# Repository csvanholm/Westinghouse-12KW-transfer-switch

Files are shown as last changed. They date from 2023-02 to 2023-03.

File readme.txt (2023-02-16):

I don't know if anybody else finds this useful? but if you do, please feel free to use this anyway you like.
I have included the schematic pdf file as well as the Kicad.sch file.
I build this on a bread board so I didn't bother with making a PCB for a one off project, but that would be easy to do 
if anyone feels the urge to do so. 

To compile this code you need to install the pico-sdk and the toolchain
there are several good tutorials on YouTube about this. (I like this one) https://www.youtube.com/watch?v=mUF9xjDtFfY

After you installed the toolchain
Create a project source directory and copy the Program.cpp and CMakeLists.txt into it.
Create a subdirectory under the source directory called build 
go into the build directory and run the command: cmake -G "Ninja" ..

After cmake is done creating the build system
Then run the command: ninja
this should build the code and generate a westinghouse12k.uf2 file   

these are the commands 
md MySrcDir
cd MySrcDir
copy Program.cpp and CMakeLists.txt files into this directory
md build
cd build
cmake -G "Ninja" ..
ninja

This controller was designed using a Pico RP2040 with a few extra external components to start,stop and detect power
of the Westinghouse WGen9500DF generator via the build-in smart switch port from a transfer-switch relay contact 
that will close when utility power fails and open when power is present.

The generator is normally started manaully using a start pushbutton or a key fob remote starter, but
it could not be hooked up directly to the transfer-switch relay since the generator needs a pulse
of a specific length to start and longer pulse stop the generator. 

The controller was designed with the following features.

1) After powering up it will wait for the generator controller to become active before 
   sending a start pulse, this is necessary because the generator controller does not
   accept commands right after power-up.

2) The Controller will try to start the generator up to 3 times if it fails after that the controller will
   "lockup" and blink all LEDs this is done to prevent draining the battery with infinite restart attempts. 
   if the generator runs out of gas or fails for some other mechanical reason (such as forgetting to open the gas spigot) 
   (Lockup is reset by turning the power off and on again)

3) When power returns the controller will run the generator in "cool down" mode for 40 seconds before stopping it,
   if power fails during cool-down, it will just keep running and exit cool-down mode.

best of luck 

carsten svanholm
csvanholm@comcast.net

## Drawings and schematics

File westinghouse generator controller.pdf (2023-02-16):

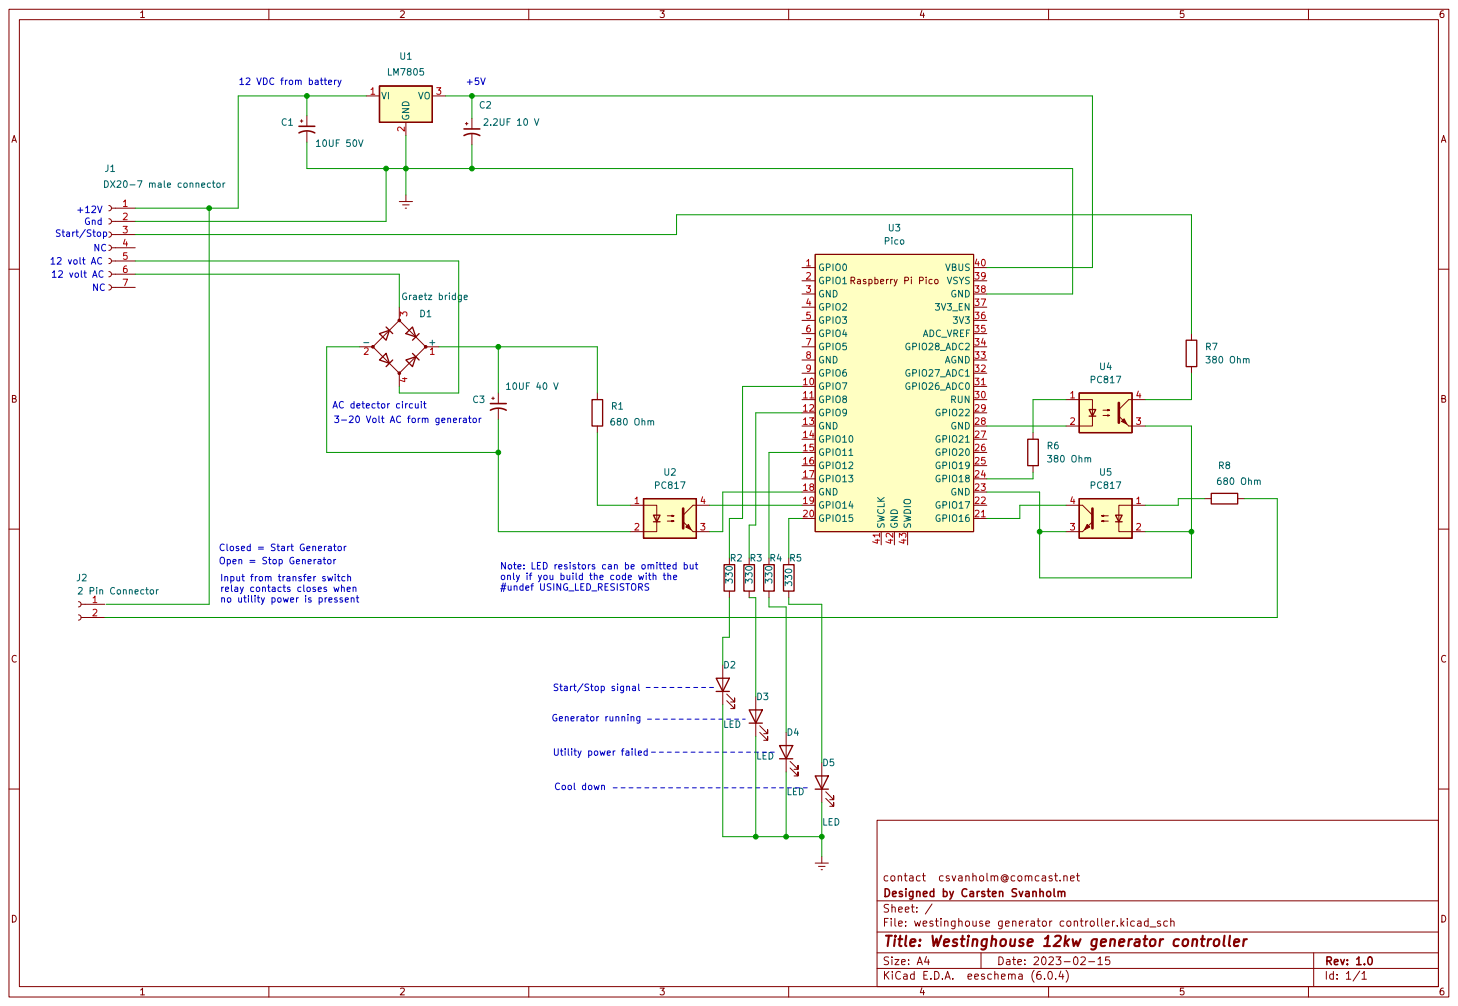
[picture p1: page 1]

Start/Stop signal AC detector circuit 12 VDC from battery

Start/Stop +12VNC
no utility power is pressent GndNC

3-20 Volt AC form generator

Note: LED resistors can be omitted but only if you build the code with the #undef USING_LED_RESISTORS

Input from transfer switch
relay contacts closes when

File: westinghouse generator controller.kicad_sch Sheet: / Designed by Carsten Svanholm

Id: 1/1 Title: Westinghouse 12kw generator controller

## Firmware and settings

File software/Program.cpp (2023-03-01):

#include "pico/stdlib.h"


//#undef USING_LED_RESISTORS     
#define USING_LED_RESISTORS

const uint GENERATOR_RUNNING    = 14;
const uint LINE_POWER_FAIL      = 16;
const uint START_STOP_RELAY     = 18;

// led port
const uint LED_PIN    = PICO_DEFAULT_LED_PIN;  // onboard led
const uint LED_BLUE   = 15;
const uint LED_RED    = 11;
const uint LED_YELLOW = 9;
const uint LED_WHITE  = 7;


class Generator
{
 public:
  Generator() { InitIoPins(); }

 private:
  bool m_GeneartorRunning=false;
  bool m_GenPowerRequested=false;
  uint m_CoolDownCounter = 0;
  uint m_StartCounter = 0;
  uint m_FailedStartRetryCounter = 0;
  uint m_TicksSinceStart = 0;
  uint m_GeneratorPowerStabel = 0;
  
  void PulseStartButton();
  void PulseStopButton();
  void AliveBlink();
  void InitIoPins();
  void ReadInputs();
  void Led(uint id,bool state);
  void BlinkFailure();
 
 public:
 void RunOneTick();
};


void Generator::PulseStartButton()
{
 Led(LED_WHITE,1);
 gpio_put(START_STOP_RELAY, 1);
 sleep_ms(1200);  // 1200 ms to start
 gpio_put(START_STOP_RELAY, 0);
 Led(LED_WHITE,0);
}

void Generator::PulseStopButton()
{
 Led(LED_WHITE,1);
 gpio_put(START_STOP_RELAY, 1);
 sleep_ms(2500);  // 2500 ms to stop  
 gpio_put(START_STOP_RELAY, 0);
 Led(LED_WHITE,0);
}


void Generator::Led(uint id,bool state)
{
 #ifdef USING_LED_RESISTORS
  gpio_put(id,state); 
 #else
 if (state) 
 {
   gpio_pull_up(id); 
 } else  
 {  
  gpio_pull_down(id);  
 }
 #endif
}


void Generator::AliveBlink()  
{
 gpio_put(LED_PIN, 1);
 sleep_ms(5);             // blink onboard LED for 5 ms to indicate the main loop is running 
 gpio_put(LED_PIN, 0);
 if (m_CoolDownCounter>0) // update status LEDS (if you installed them, they are not required)
 {
  Led(LED_BLUE,!gpio_get(LED_BLUE)); // make cool down led blink if we are in cool-down mode before stopping generator
 } else
 {
   Led(LED_BLUE,0);
 }
 if (m_GeneratorPowerStabel > 0)
 {
   Led(LED_YELLOW,!gpio_get(LED_YELLOW));
 } else
 {
  Led(LED_YELLOW,m_GeneartorRunning);
 }
 Led(LED_RED,m_GenPowerRequested);
}


void Generator::BlinkFailure()
{
 bool state = true;
 for (int a=0; a<10; a++)
 {
  Led(LED_BLUE,state);
  Led(LED_RED,state);
  Led(LED_YELLOW,state);
  Led(LED_WHITE,state);
  sleep_ms(40);
  state=!state;
 }
}



void Generator::InitIoPins()
{
  stdio_init_all();

  gpio_init(LED_PIN);
  gpio_set_dir(LED_PIN, GPIO_OUT);

  gpio_init(GENERATOR_RUNNING);
  gpio_set_dir(GENERATOR_RUNNING, GPIO_IN);
  gpio_pull_up(GENERATOR_RUNNING);

  gpio_init(LINE_POWER_FAIL);
  gpio_set_dir(LINE_POWER_FAIL, GPIO_IN);
  gpio_pull_up(LINE_POWER_FAIL);

  gpio_init(START_STOP_RELAY);
  gpio_set_dir(START_STOP_RELAY, GPIO_OUT);
  
  // CRITICAL!!! The indicator LEDs can be connected directly to the RP2040 ports without a resistor if we use the internal pullup resistor 
  // in the chip.
  // LED ports need to be set as inputs if we are using the internal pullup resistor to drive the led by switching between 
  // pull_up to turn it on and pull_down to turn it off
  // this will draw just enough current to turn the LED's on but technically too weak to drive green LED's.
  // if you want brighter LED's you need to use a 380 to 680 ohm resistor between the RP2040 port and the LED's and define USING_LED_RESISTORS
  // at the top of this file  
  #ifndef USING_LED_RESISTORS
  gpio_init(LED_BLUE);
  gpio_set_dir(LED_BLUE,GPIO_IN);
  gpio_pull_down(LED_BLUE);

  gpio_init(LED_RED);
  gpio_set_dir(LED_RED,GPIO_IN);
  gpio_pull_down(LED_RED);
  
  gpio_init(LED_YELLOW);
  gpio_set_dir(LED_YELLOW,GPIO_IN);
  gpio_pull_down(LED_YELLOW);

  gpio_init(LED_WHITE);
  gpio_set_dir(LED_WHITE,GPIO_IN);
  gpio_pull_down(LED_WHITE);
 
 #else
  gpio_init(LED_BLUE);
  gpio_set_dir(LED_BLUE,GPIO_OUT);

  gpio_init(LED_RED);
  gpio_set_dir(LED_RED,GPIO_OUT);
  
  gpio_init(LED_YELLOW);
  gpio_set_dir(LED_YELLOW,GPIO_OUT);
  
  gpio_init(LED_WHITE);
  gpio_set_dir(LED_WHITE,GPIO_OUT);
 
 #endif
}

void Generator::ReadInputs()
{
 // The starter cranking the engine might energize the low voltage coil so we dont want to assume the generator is running yet so just wait a few seconds.   
 // transition from no power to power state but assume a 5 second delay before we act on the change input to ensure engine is running
 if (!gpio_get(GENERATOR_RUNNING) && !m_GeneartorRunning) // if current state is different than last state
 {
  if (m_GeneratorPowerStabel > 6)
  {
    m_GeneartorRunning   = !gpio_get(GENERATOR_RUNNING);  // inputs are active low or inverted 
  } else
  {
   m_GeneratorPowerStabel++;
  }
 } else
 {
  m_GeneartorRunning   = !gpio_get(GENERATOR_RUNNING);    // active low
  m_GeneratorPowerStabel = 0;
 }
 m_GenPowerRequested  = !gpio_get(LINE_POWER_FAIL);
}


void Generator::RunOneTick()
{
 m_TicksSinceStart++;
 if (m_FailedStartRetryCounter >= 3)  // lockup the controler to prevent repeated restarts attempts (on out of gas) to avoid draining the battery     
 {
  BlinkFailure();
  return;
 }
 ReadInputs();                 // get the current state 
 AliveBlink();                 // blink indicators
 if (m_GeneartorRunning)       // if generator is running and power is requested just keep running and reset the cool down counter
 {
  m_StartCounter=0;
  m_FailedStartRetryCounter=0; 
  if (m_GenPowerRequested)
  {
   m_CoolDownCounter = 0;
  } else
  {
   m_CoolDownCounter++;         // if generator is running but power is no longer requested allow the generator to cool down for 40 seconds before stopping it. 
   if (m_CoolDownCounter >= 80) // this will also take care of power flickering in the first seconds after utility power returns
   {
    PulseStopButton();          // signale the generator to stop
    m_CoolDownCounter = 0;
   }
  }
 } else                         // Generator not running.  
 {
  m_CoolDownCounter = 0;
  if (m_GenPowerRequested && m_TicksSinceStart > 15 && m_GeneratorPowerStabel==0) // we have to wait for the generator controller to become active
  {
    if (m_StartCounter==0)       // Only send one start Pulse to generator and wait for the generator to start
    {
      PulseStartButton();
    }
    m_StartCounter++;
    if (m_StartCounter > 60 && m_FailedStartRetryCounter<3)    // if the Generator failed to start we will try again after 30 seconds after the 3rd attempt we goto into fail state (blink all the leds)
    {
      m_StartCounter=0;         
      m_FailedStartRetryCounter++;
    }
  } else
  {
    m_StartCounter=0;       
    m_FailedStartRetryCounter=0; 
  }
 }
}


int main() 
{
 Generator gen;
 while (true) 
 {
   gen.RunOneTick();
   sleep_ms(500);
 };
 return 0; 
}
